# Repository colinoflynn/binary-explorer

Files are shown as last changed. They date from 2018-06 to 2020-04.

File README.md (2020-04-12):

# Binary Explorer #

The Binary Explorer board is based on a previous Kickstarter project, and is designed to provide a useful platform for learning about digital logic. Compared to the previous version, the CPLD has been changed to an Altera MAX II which can be used with more recent design software (including on Windows 10). Note the old ("rev 02") version is completely incompatible with the current version, as the entire CPLD and programming interface has changed.

Binary Explorer includes:

- Altera MAX II CPLD which can be disabled to bypass outputs
- Breadboard for building logic circuits
- Switches, LEDs, and 7-segment displays
- Clocks for CPLD

The following is the old rev design, which looks almost identical from the top-side:
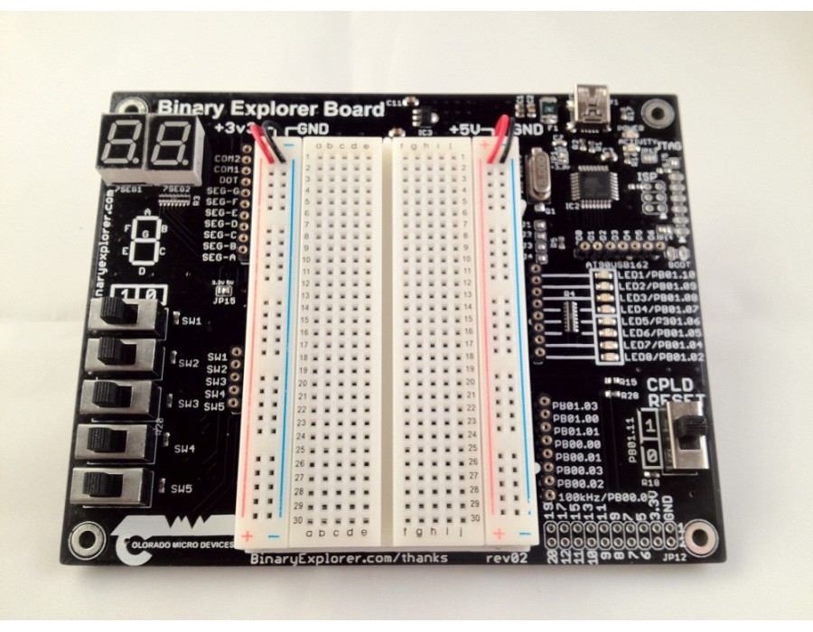
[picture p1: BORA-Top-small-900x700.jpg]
BORA Board


## Reference Designs / Examples ##

A number of templates/examples are provided for the Altera Quartus software. Always use these templates, as they contain considerable critical configuration regarding the device in use and board-specific setting (including pinouts and use of global disable).

If you fail to use these templates and things break, **we will laugh at you when they break**. 

## Using Breadboard ##

To use the breadboard, it's important to set the CPLD to "OFF". The "OFF" position should disable the I/O drivers on the CPLD, but it relies on the CPLD having been configured based on one of the template files.

If you do not set the CPLD to "OFF", or have programmed it with invalid code, you could find certain pins are being driven high/low against your will.

**NEVER use 5.0V on this board** - all I/O will only survive with 3.3V. The board does not include a 5.0V source to avoid this risk, but **DO NOT wire in an external 5.0V source**.

Be sure to **confirm any logic chips you are using** will operate at 3.3V OK.

## USB CPLD Programmer ##

The USB CPLD programming interface is provided thanks to work published at http://sa89a.net/mp.cgi/ele/ub.htm . This pushed the CPLD programming onto one of the lowest-cost USB interface chips which made this entire project possible.

We have adapted this design, with some very minor firmware changes to provide a slow and fast clock to the CPLD. This is often useful during development.

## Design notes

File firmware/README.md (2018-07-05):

# USB Blaster Firmware #

The USB Blaster firmware is based entirely on published work from http://sa89a.net/mp.cgi/ele/ub.htm

The firmware in this repository is a copy of the "0.7" release, and has been slightly updated to include two additional clock outputs:

1) A 50 KHz "fast clock"
2) A 1 Hz "slow clock"

These two clocks are routed to the CPLD, and can be used during development to clock your logic circuits.

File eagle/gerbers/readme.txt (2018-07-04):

Date: June 24, 2018

**********************************************************
PCB Specifications:
 * ROHS Compliant (Lead Free)
 * UL94V-0 Compliant
 * Material: FR-4, 1.6mm
 * Top/Bottom Copper: 0.5 Oz or 1 Oz
 * Top/Bottom Silkscreen Colour: *
 * Top/Bottom Soldermask Colour: Black
 
**********************************************************
Layer Stackup:
 * Top Silkscreen (digital explorer_SILKSCREEN_TOP.gbr)
 * Top Soldermask (digital explorer_SOLDERMASK_BOTTOM.gbr)
 * Top Copper (digital explorer_COPPER_TOP.gbr)
 **** FR4 Material
 * Bottom Copper (digital explorer_COPPER_BOTTOM.gbr)
 * Bottom Soldermask (digital explorer_SOLDERMASK_BOTTOM.gbr)
 * Bottom Silkscreen (digital explorer_SILKSCREEN_BOTTOM.gbr)
 
 Drill file: digital explorer.ncdrill

**********************************************************
Gerber Plotfile Info:
	 Coordinate Format : 2.4
	 Coordinate Units  : Inch
	 Data Mode         : Absolute
	 Zero Suppression  : None
	 End Of Block      : *

NC-Drill File Info:
	 Data Mode         : Absolute
	 Units             : 1/10000 Inch
	 Code  Size       used

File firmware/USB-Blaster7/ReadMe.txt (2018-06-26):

USB-Blasterもどき
マイクロチップのUSBファームウェアVer.2.8をベースに作っています。
再コンパイルする場合下記の環境が必要です。
・MPLAB IDE
・C18 Compiler
・Microchip USB Firmware Ver.2.8(同梱していますので用意する必要はありません)
上記ツールをインストールした上でプロジェクトファイルを開き、
Configure->SelectDevice画面でPIC18F14k50を選択してください。

SPIモジュールの利用と、バイト単位でのIOのため、IOピンが固定となっています。
「BlasterMacros.h」でのピン定義はあくまで命名のためです。
ここだけ変更してもピン配置の変更にはなりません。

・SPI周波数変更
　「BlasterMacros.h」ファイルの13-14行目で切り替え可能です。

・PIO/SPI切り替え
　JTAG通信を高速化するため、PICのMSSPモジュールをSPIモードで利用しています。
　「BlasterMacros.h」ファイル23行目の#define USE_SPIをコメントアウトすると
　SPIモジュールを使わず、プログラムでIOを行います。
　速度は遅くなるので、できればSPIを利用することをお勧めします。

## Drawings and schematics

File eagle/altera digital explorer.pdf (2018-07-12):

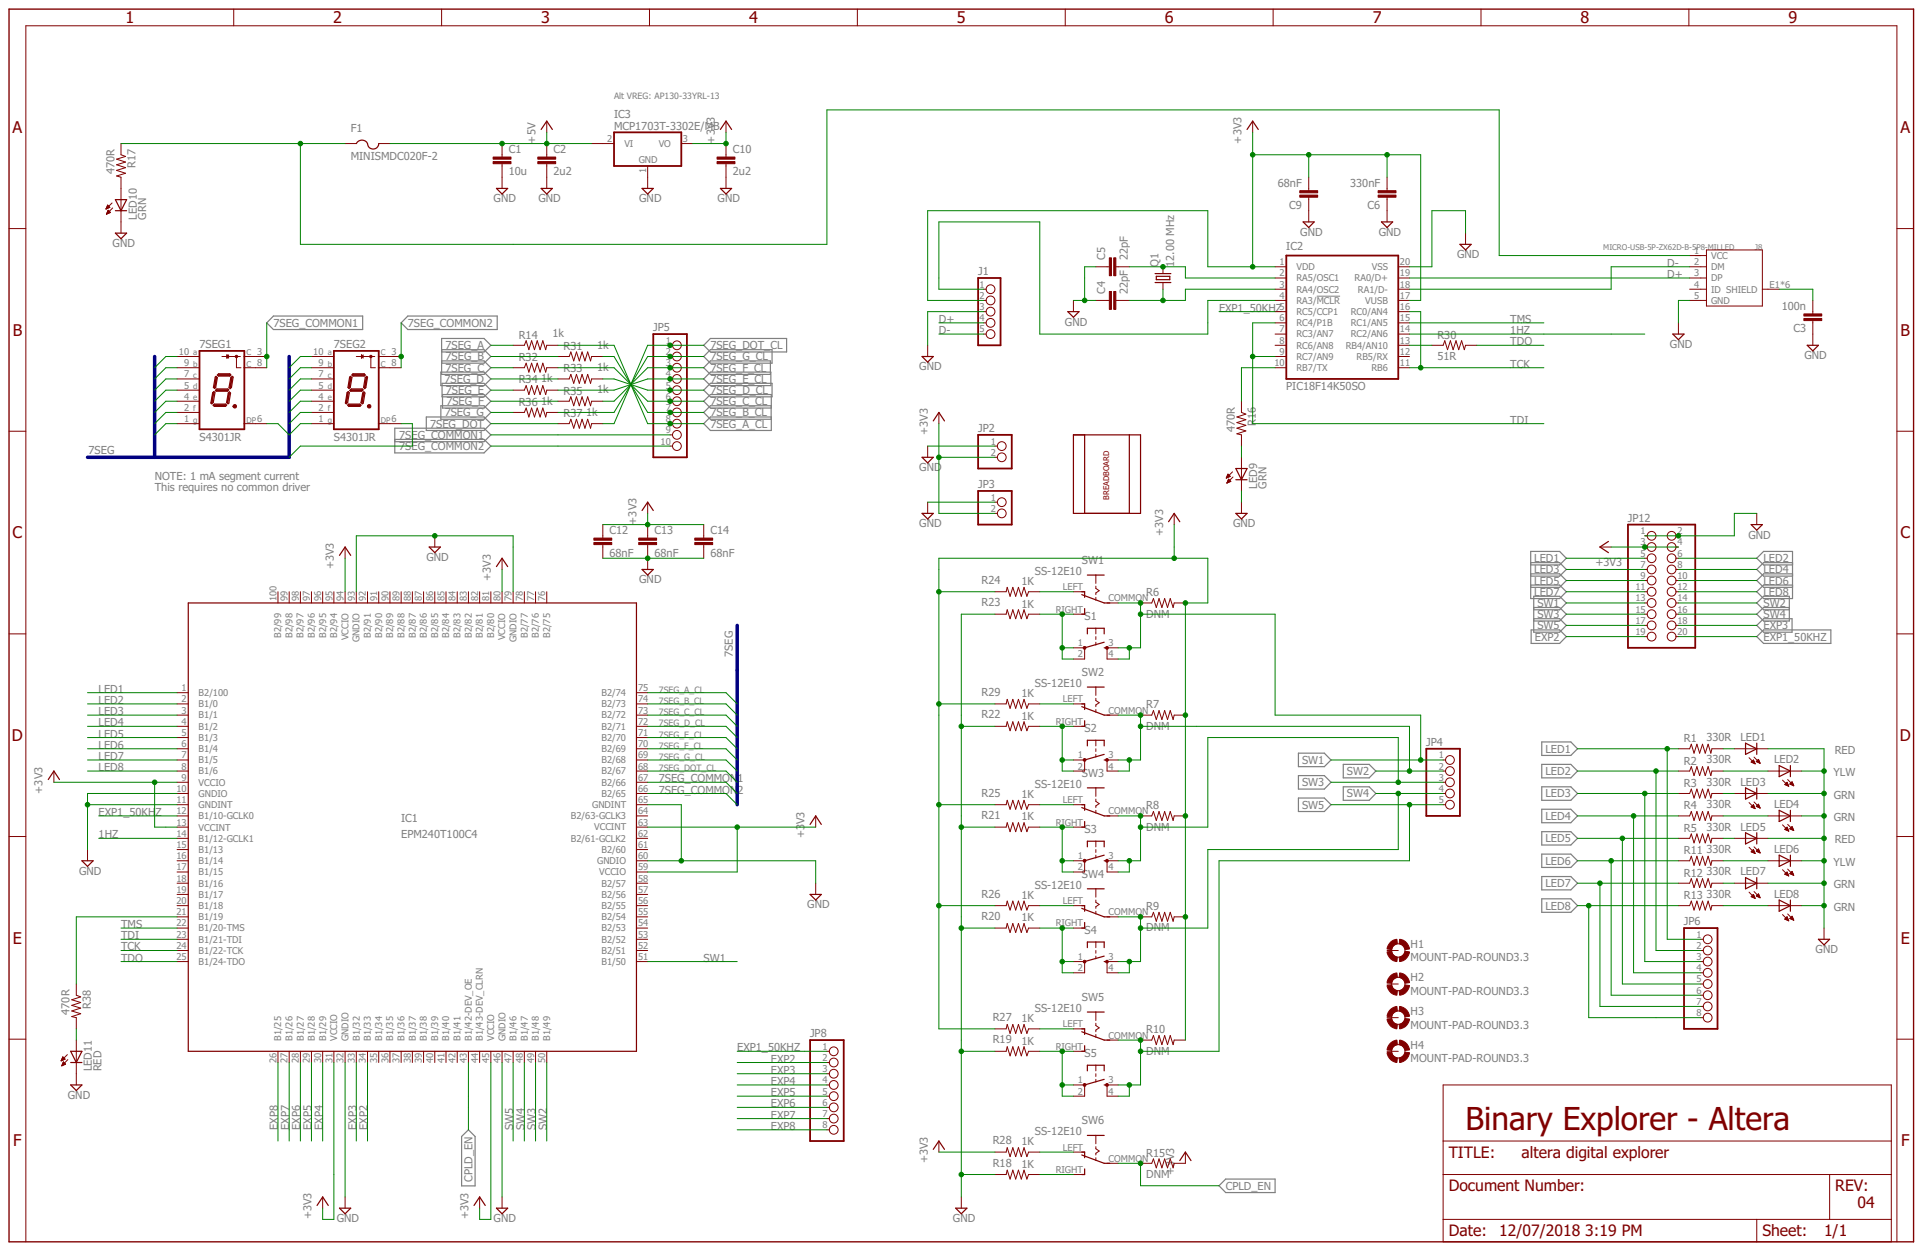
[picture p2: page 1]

NOTE: 1 mA segment current This requires no common driver 7SEG

GND MOUNT-PAD-ROUND3.3 MOUNT-PAD-ROUND3.3 MOUNT-PAD-ROUND3.3 MOUNT-PAD-ROUND3.3

REV: TITLE: Document Number: altera digital explorer

Date: 12/07/2018 3:19 PM | Sheet: 1/1

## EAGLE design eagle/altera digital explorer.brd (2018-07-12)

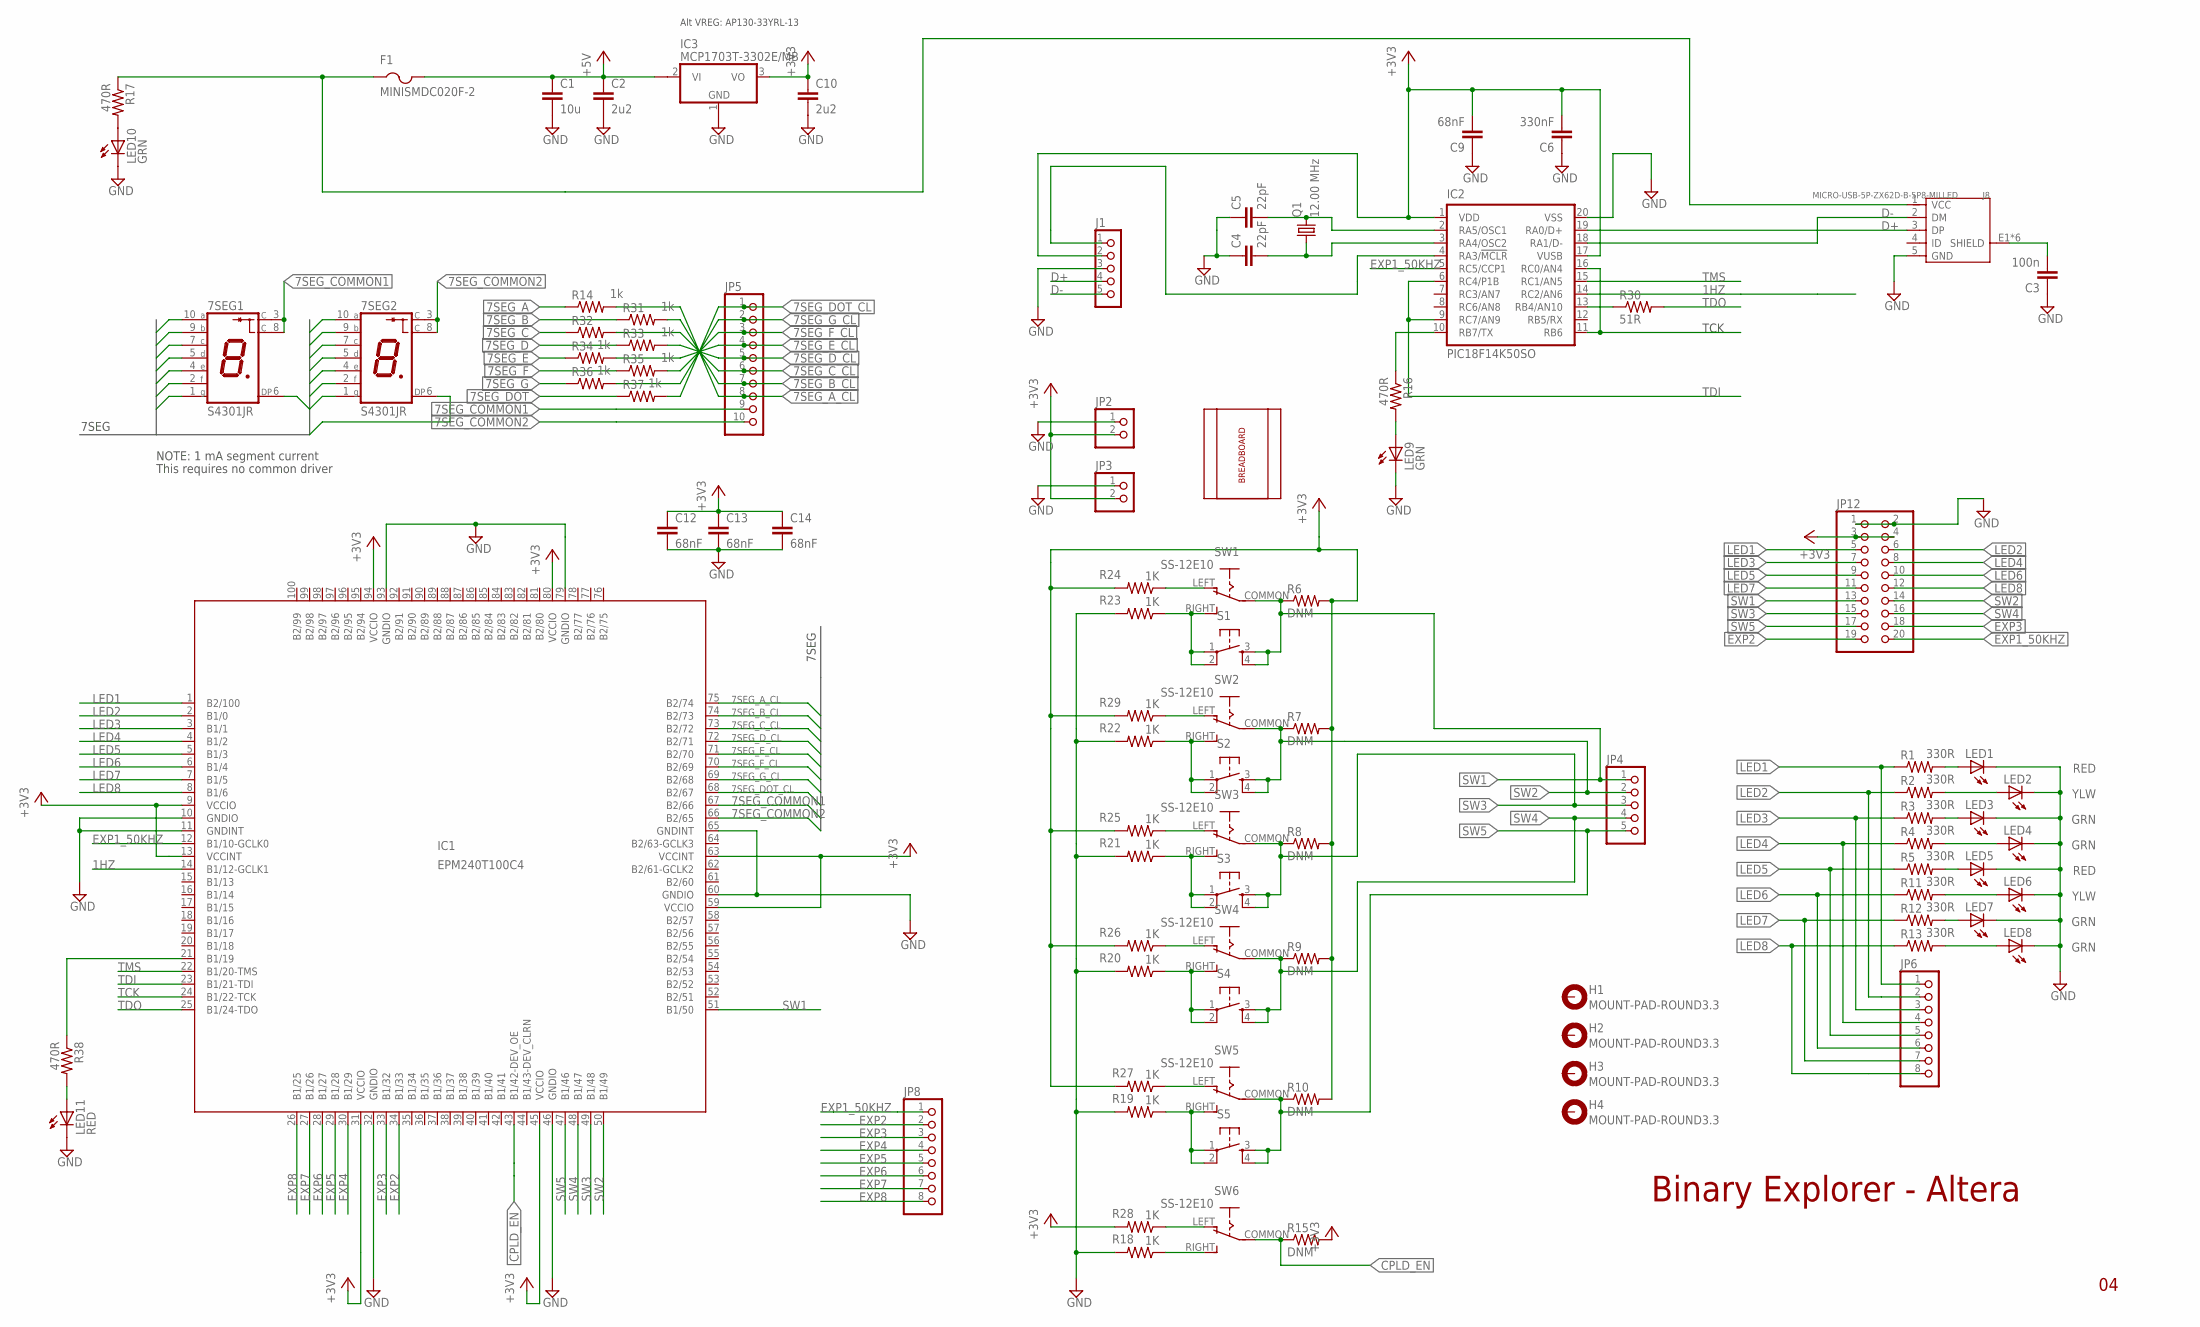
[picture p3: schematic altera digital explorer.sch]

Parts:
7SEG1, 7SEG2: S4301JR; S4301B
C1: 10u; C0805
C2, C10: 2u2; C0805
C3: 100n; C0603
C4, C5: 22pF; C0603
C6: 330nF; C0603
C9, C12, C14: 68nF; C0603
C13: 68nF; C0603K
F1: MINISMDC020F-2; 1812
H1, H2, H3, H4: MOUNT-PAD-ROUND3.3; 3,3-PAD
IC1: EPM240T100C4; TQFP100
IC2: PIC18F14K50SO; SO20
IC3: MCP1703T-3302E/MB; SOT89
J1: CON_HEADER_1X05-PTH; M1X5
J8: MICRO-USB-5P-ZX62D-B-5P8-MILLED; B-SMD-5P-TH-MILLED; MPN ZX62D-B-5P8
JP2, JP3: PINHD-1X2; 1X02
JP4: PINHD-1X5; 1X05
JP5: PINHD-1X10; 1X10
JP6, JP8: PINHD-1X8; 1X08
JP12: PINHD-2X10; 2X10
LED1, LED5, LED11: RED; CHIP-LED0805
LED2, LED6: YLW; CHIP-LED0805
LED3, LED4, LED7, LED8, LED9, LED10: GRN; CHIP-LED0805
Q1: 12.00 MHz; HC49UP; MPN ATS080BSM-1
R1, R2, R3, R4, R5, R11, R12, R13: 330R; R0603
R6, R7, R8, R9, R10, R15: DNM; R0603
R14, R31, R33, R34, R35, R36, R37: 1k; R0603
R16, R17, R38: 470R; R0603
R18, R19, R20, R21, R22, R23, R24, R25, R26, R27, R28, R29: 1K; R0603
R30: 51R; R0603
R32: R-US_R0603; R0603
S1, S2, S3, S4, S5: TAC_SWITCHPTH; TACTILE-PTH
SW1, SW2, SW3, SW4, SW5, SW6: SS-12E10
U$1: BB-400TP

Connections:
1HZ: IC1.14 (B1/12-GCLK1), IC2.14 (RC2/AN6)
7SEG_A: 7SEG1.10 (A), 7SEG2.10 (A), R14.1
7SEG_A_CL: IC1.75 (B2/74), JP5.8, R14.2
7SEG_B: 7SEG1.9 (B), 7SEG2.9 (B), R31.1
7SEG_B_CL: IC1.74 (B2/73), JP5.7, R31.2
7SEG_C: 7SEG1.7 (C), 7SEG2.7 (C), R32.1
7SEG_COMMON1: 7SEG1.3 (C), 7SEG1.8 (C), IC1.67 (B2/66), JP5.9
7SEG_COMMON2: 7SEG2.3 (C), 7SEG2.8 (C), IC1.66 (B2/65), JP5.10
7SEG_C_CL: IC1.73 (B2/72), JP5.6, R32.2
7SEG_D: 7SEG1.5 (D), 7SEG2.5 (D), R33.1
7SEG_DOT: 7SEG1.6 (DP), 7SEG2.6 (DP), R37.1
7SEG_DOT_CL: IC1.68 (B2/67), JP5.1, R37.2
7SEG_D_CL: IC1.72 (B2/71), JP5.5, R33.2
7SEG_E: 7SEG1.4 (E), 7SEG2.4 (E), R34.1
7SEG_E_CL: IC1.71 (B2/70), JP5.4, R34.2
7SEG_F: 7SEG1.2 (F), 7SEG2.2 (F), R35.1
7SEG_F_CL: IC1.70 (B2/69), JP5.3, R35.2
7SEG_G: 7SEG1.1 (G), 7SEG2.1 (G), R36.1
7SEG_G_CL: IC1.69 (B2/68), JP5.2, R36.2
+3V3: C6.2, C9.2, C10.1, C12.1, C13.1, C14.1, IC1.9 (VCCIO), IC1.13 (VCCINT), IC1.31 (VCCIO), IC1.45 (VCCIO), IC1.59 (VCCIO), IC1.63 (VCCINT), IC1.80 (VCCIO), IC1.94 (VCCIO), IC2.1 (VDD), IC2.17 (VUSB), IC3.3 (VO), J1.2, JP2.2, JP3.2, JP12.3, JP12.4, R6.2, R7.2, R8.2, R9.2, R10.2, R15.2, R24.2, R25.2, R26.2, R27.2, R28.2, R29.2
+5V: C1.1, C2.1, F1.2, IC3.2@1 (VI1)
CPLD_EN: IC1.43 (B1/42-DEV_OE), R15.1, SW6.COMMON
D+: IC2.19 (RA0/D+), J1.4, J8.3 (DP)
D-: IC2.18 (RA1/D-), J1.5, J8.2 (DM)
EXP1_50KHZ: IC1.12 (B1/10-GCLK0), IC2.5 (RC5/CCP1), JP8.1, JP12.20
EXP2: IC1.34 (B1/33), JP8.2, JP12.19
EXP3: IC1.33 (B1/32), JP8.3, JP12.18
EXP4: IC1.30 (B1/29), JP8.4
EXP5: IC1.29 (B1/28), JP8.5
EXP6: IC1.28 (B1/27), JP8.6
EXP7: IC1.27 (B1/26), JP8.7
EXP8: IC1.26 (B1/25), JP8.8
GND: C1.2, C2.2, C3.1, C4.1, C5.1, C6.1, C9.1, C10.2, C12.2, C13.2, C14.2, IC1.10 (GNDIO), IC1.11 (GNDINT), IC1.32 (GNDIO), IC1.46 (GNDIO), IC1.60 (GNDIO), IC1.65 (GNDINT), IC1.79 (GNDIO), IC1.93 (GNDIO), IC2.20 (VSS), IC3.1 (GND), J1.3, J8.5 (GND), JP2.1, JP3.1, JP12.1, JP12.2, LED1.C, LED2.C, LED3.C, LED4.C, LED5.C, LED6.C, LED7.C, LED8.C, LED9.C, LED10.C, LED11.C, R18.2, R19.2, R20.2, R21.2, R22.2, R23.2
LED1: IC1.1 (B2/100), JP6.1, JP12.5, R1.1
LED2: IC1.2 (B1/0), JP6.2, JP12.6, R2.1
LED3: IC1.3 (B1/1), JP6.3, JP12.7, R3.1
LED4: IC1.4 (B1/2), JP6.4, JP12.8, R4.1
LED5: IC1.5 (B1/3), JP6.5, JP12.9, R5.1
LED6: IC1.6 (B1/4), JP6.6, JP12.10, R11.1
LED7: IC1.7 (B1/5), JP6.7, JP12.11, R12.1
LED8: IC1.8 (B1/6), JP6.8, JP12.12, R13.1
unnamed: IC2.10 (RB7/TX), R16.1
unnamed: LED4.A, R4.2
unnamed: IC2.13 (RB4/AN10), R30.1
unnamed: IC1.21 (B1/19), R38.1
unnamed: R22.1, S2.1, S2.2, SW2.RIGHT (S)
unnamed: F1.1, J8.1 (VCC), R17.1
unnamed: C3.2, J8.E1 (SHIELD), J8.E2 (SHIELD), J8.P$1 (SHIELD), J8.P$2 (SHIELD), J8.P$3 (SHIELD), J8.P$4 (SHIELD)
unnamed: LED11.A, R38.2
unnamed: IC2.4 (RA3/!MCLR!), J1.1
unnamed: LED9.A, R16.2
unnamed: C5.2, IC2.2 (RA5/OSC1), Q1.2
unnamed: C4.2, IC2.3 (RA4/OSC2), Q1.1
unnamed: R20.1, S4.1, S4.2, SW4.RIGHT (S)
unnamed: LED10.A, R17.2
unnamed: R21.1, S3.1, S3.2, SW3.RIGHT (S)
unnamed: R18.1, SW6.RIGHT (S)
unnamed: R19.1, S5.1, S5.2, SW5.RIGHT (S)
unnamed: LED1.A, R1.2
unnamed: R23.1, S1.1, S1.2, SW1.RIGHT (S)
unnamed: LED2.A, R2.2
unnamed: LED3.A, R3.2
unnamed: LED5.A, R5.2
unnamed: LED6.A, R11.2
unnamed: LED7.A, R12.2
unnamed: LED8.A, R13.2
unnamed: R24.1, SW1.LEFT (O)
unnamed: R25.1, SW3.LEFT (O)
unnamed: R26.1, SW4.LEFT (O)
unnamed: R27.1, SW5.LEFT (O)
unnamed: R28.1, SW6.LEFT (O)
unnamed: R29.1, SW2.LEFT (O)
SW1: IC1.51 (B1/50), JP4.1, JP12.13, R6.1, S1.3, S1.4, SW1.COMMON
SW2: IC1.50 (B1/49), JP4.2, JP12.14, R7.1, S2.3, S2.4, SW2.COMMON
SW3: IC1.49 (B1/48), JP4.3, JP12.15, R8.1, S3.3, S3.4, SW3.COMMON
SW4: IC1.48 (B1/47), JP4.4, JP12.16, R9.1, S4.3, S4.4, SW4.COMMON
SW5: IC1.47 (B1/46), JP4.5, JP12.17, R10.1, S5.3, S5.4, SW5.COMMON
TCK: IC1.24 (B1/22-TCK), IC2.11 (RB6), IC2.16 (RC0/AN4)
TDI: IC1.23 (B1/21-TDI), IC2.6 (RC4/P1B), IC2.9 (RC7/AN9)
TDO: IC1.25 (B1/24-TDO), R30.2
TMS: IC1.22 (B1/20-TMS), IC2.15 (RC1/AN5)

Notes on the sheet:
7SEG
Alt VREG: AP130-33YRL-13
TCK
NOTE: 1 mA segment current
This requires no common driver
Binary Explorer - Altera

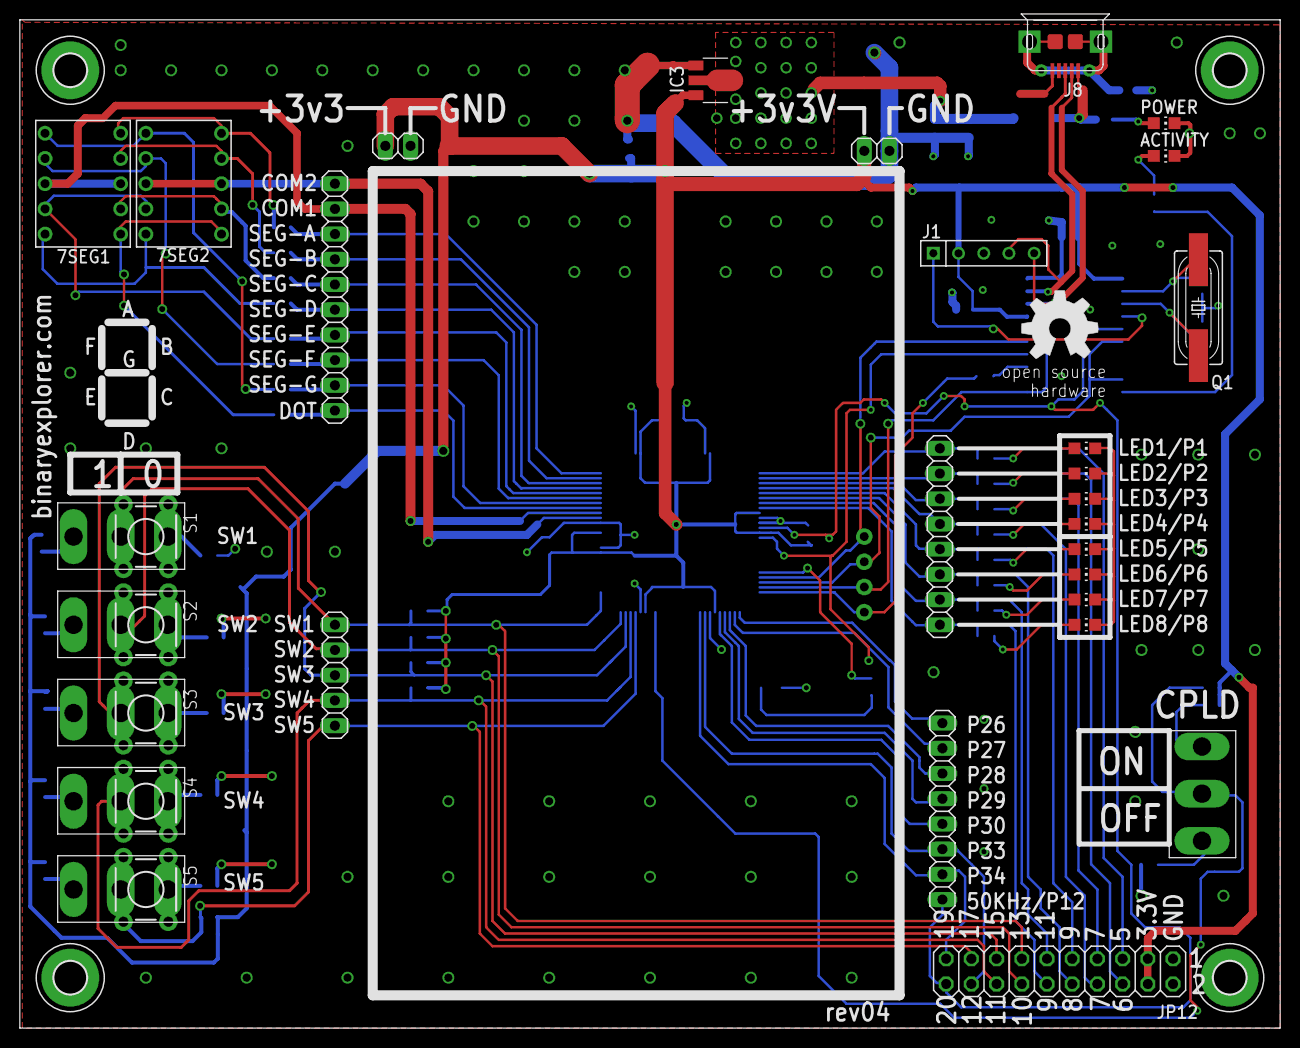
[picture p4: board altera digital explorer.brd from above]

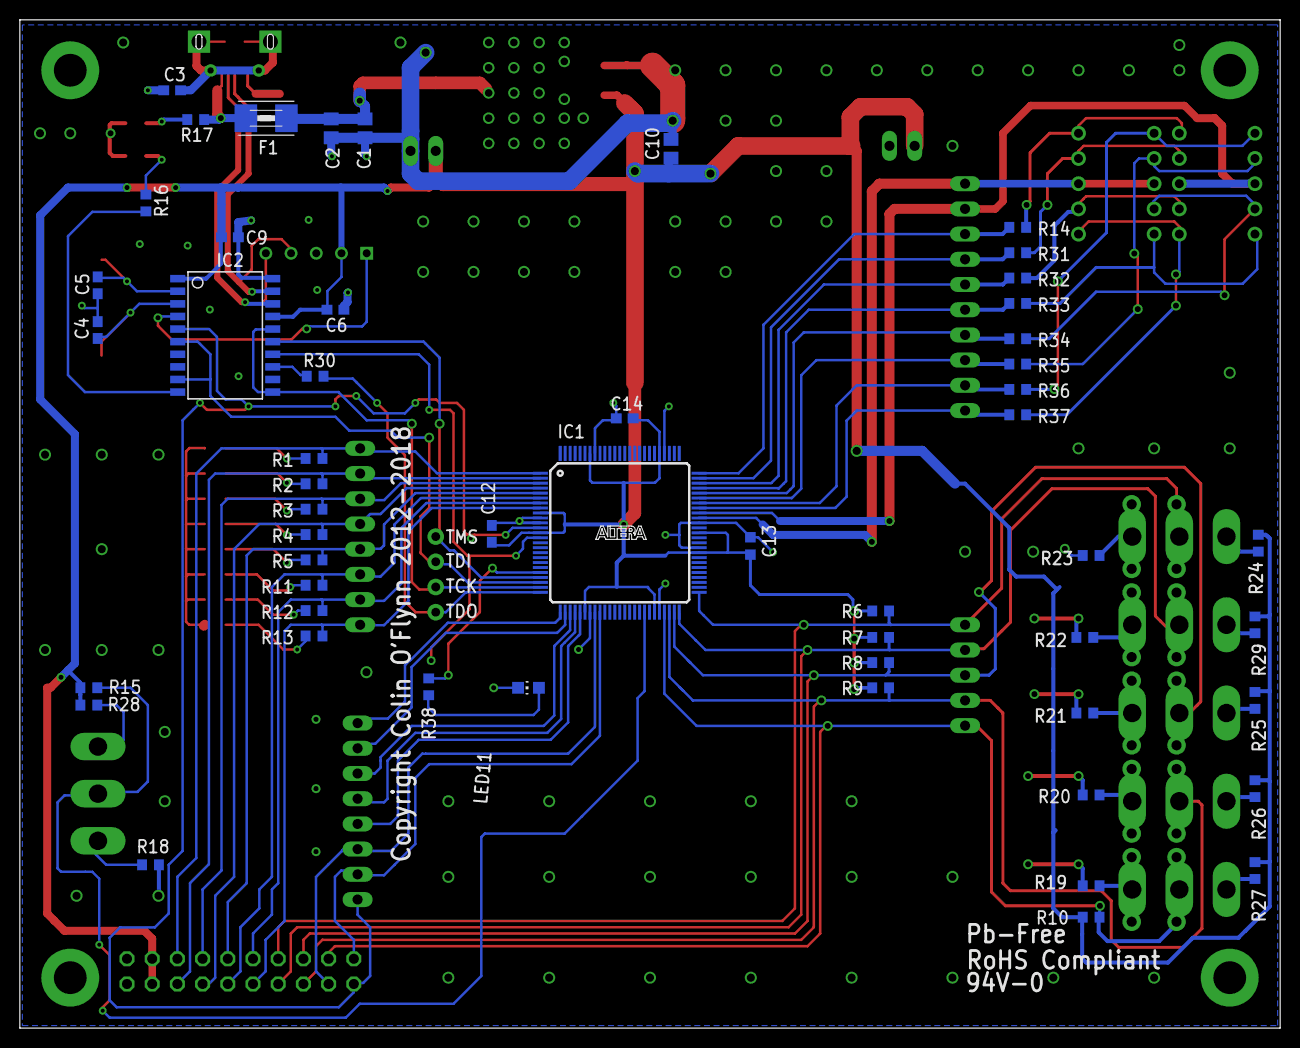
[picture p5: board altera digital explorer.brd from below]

Board: 2 copper layers, 127.0 x 101.6 mm, 93 parts (53 on the bottom side), 81 nets.

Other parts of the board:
U$2: OSHW_8MM

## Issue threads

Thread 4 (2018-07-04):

PCB - bad PIC connections

colinoflynn, 2018-07-04:
PIC connections didn't follow original page but an updated one, the updated one might be wrong. Seems to need double-connections to actually work.

PCB has been modded and eagle updated, but need to commit this and test.

Closed 2018-07-05.

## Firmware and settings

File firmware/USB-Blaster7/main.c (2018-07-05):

// main.c

/** INCLUDES *******************************************************/
#include "./USB/usb.h"
#include "HardwareProfile.h"
//#include "GenericTypeDefs.h"
//#include "Compiler.h"
//#include "usb_config.h"
//#include "USB/usb_device.h"

#include "bitreverse.h"
#include "emu_ft245_eeprom.h"
#include "BlasterMacros.h"

/** CONFIGURATION **************************************************/
#pragma config CPUDIV = NOCLKDIV
#pragma config USBDIV = OFF
#pragma config FOSC   = HS
#pragma config PLLEN  = ON
#pragma config FCMEN  = OFF
#pragma config IESO   = OFF
#pragma config PWRTEN = OFF
#pragma config BOREN  = OFF
#pragma config BORV   = 30
//#pragma config VREGEN = ON
#pragma config WDTEN  = OFF
#pragma config WDTPS  = 32768
#pragma config MCLRE  = OFF
#pragma config HFOFST = OFF
#pragma config STVREN = ON
#pragma config LVP    = OFF
#pragma config XINST  = OFF
#pragma config BBSIZ  = OFF
#pragma config CP0    = OFF
#pragma config CP1    = OFF
#pragma config CPB    = OFF
#pragma config WRT0   = OFF
#pragma config WRT1   = OFF
#pragma config WRTB   = OFF
#pragma config WRTC   = OFF
#pragma config EBTR0  = OFF
#pragma config EBTR1  = OFF
#pragma config EBTRB  = OFF       

/** V A R I A B L E S **********************************************/
#pragma udata USB_VARS
BYTE OutPacket[2][64];
BYTE InPacket[1][64];
extern volatile BYTE CtrlTrfData[8];
#define ctrl_trf_buf CtrlTrfData

#pragma udata access accessram
near BYTE fifo_wp,fifo_rp;		//FIFO Write Pos / Read Pos
near BYTE acc0,acc1;			//AccessRAM for FastTemporaly
near BYTE recv_byte;			//byte count received
near BYTE jtag_byte;			//byte count fot jtag mode
near BYTE aser_byte;			//byte count fot active-serial mode
near BYTE_VAL _flags;
#define read _flags.bits.b0		//simulteneous reading flag
#define received _flags.bits.b1	//OUT Packet Received flag
#ifdef ENABLE_PPB
  #define PPB _flags.bits.b7	//current ping-pong-buffer
  #define TogglePPB() PPB=!PPB 
#else
  #define PPB 0 
  #define TogglePPB()
#endif
near BYTE bufptr;

#pragma udata GP1
BYTE InFIFO[256];

#pragma udata
USB_HANDLE USBOutHandle0;
USB_HANDLE USBOutHandle1;
USB_HANDLE USBInHandle0;

/** P R I V A T E  P R O T O T Y P E S *****************************/
void USBDeviceTasks(void);
void HighIntCode();
void LowIntCode();
void USBCBSendResume(void);

/** VECTOR REMAPPING ***********************************************/
extern void _startup(void);

//Vector Remapping for Standalone Operating
#pragma code HIGH_INTERRUPT_VECTOR = 0x08
void High_ISR(void) { _asm goto 0x1008 _endasm }

#pragma code LOW_INTERRUPT_VECTOR = 0x18
void Low_ISR(void) { _asm goto 0x1018 _endasm }

//Vector Remapping for MCHIP Generic Bootloader
#pragma code GEN_RESET_VECTOR=0x800
void GEN_Reset(void) { _asm goto _startup _endasm }

#pragma code GEN_HIGH_INTERRUPT_VECTOR=0x808
void GEN_HighInt(void) { _asm goto HighIntCode _endasm }

#pragma code GEN_LOW_INTERRUPT_VECTOR=0x818
void GEN_LowInt(void) { _asm goto LowIntCode _endasm }

//Vector Remapping for MCHIP HID Bootloader
#pragma code HID_RESET_VECTOR=0x1000
void HID_Reset(void) { _asm goto _startup _endasm }

#pragma code HID_HIGH_INTERRUPT_VECTOR=0x1008
void HID_HighInt(void) { _asm goto HighIntCode _endasm }

#pragma code HID_LOW_INTERRUPT_VECTOR=0x1018
void HID_LowInt(void) { _asm goto LowIntCode _endasm }

#pragma code
	
#pragma interrupt HighIntCode
void HighIntCode() {
    static unsigned char cnt;
    
    
		//Check which interrupt flag caused the interrupt.
		//Service the interrupt, Clear the interrupt flag, Etc.
        #if defined(USB_INTERRUPT)
	    USBDeviceTasks();
        #endif

        
        if (PIR1bits.TMR1IF) {
            cnt++;
            
            if (cnt > 22){
                LATCbits.LATC2 ^= 1;
                cnt = 0;
            }
            PIR1bits.TMR1IF = 0; 
        } 
        
}	//This return will be a "retfie fast", since this is in a #pragma interrupt section 

#pragma interruptlow LowIntCode
void LowIntCode() {
		//Check which interrupt flag caused the interrupt.
		//Service the interrupt, Clear the interrupt flag, Etc. 
    
	
}	//This return will be a "retfie", since this is in a #pragma interruptlow section 

/** DECLARATIONS ***************************************************/
#pragma code

//for debug use - measure cycle counts
void test(){
	BYTE *p;
	bufptr=64;
	fifo_wp=0;
	fifo_rp=0;
	acc0=0x53;
	acc1=bitreverse[SSPBUF];	//10cy
	enqueue(acc0);		//9cy
	enqueue(acc1);		//9cy
	JTAG_Write(acc0);		//56cy
	JTAG_RW(acc0,acc1);	//73cy
	ASer_RW(acc0,acc1);	//73cy
	dequeue(InPacket[0]+2,fifo_used());	// 116cy@2byte
	fifo_wp=0;for(acc0=0;1;acc0++){enqueue(acc0);if(acc0==255)break;}
	fifo_wp=100; fifo_rp=190;
	dequeue(InPacket[0]+2,62);	//818cy@62byte
	dequeue(InPacket[0]+2,62);	//890cy@62byte
	acc1=bitreverse[OutPacket[0][bufptr++]];	//17cy
	enqueue(bitreverse[SSPBUF]);	//20cy
	Nop();
}

void main(void) {
	//IO Initialize
	ANSEL  = 0;
	ANSELH = 0;
	SLRCON = 0;

	//Port direction setup
	TRISA=0;
	TRISB=0;
	TRISC=0;
	TTDO=1;
	TADO=1;

	//Initial value setup
	OUTP=0b00011010;

	//Peripheral setup
	T0CON=0b10000000;		//On,Fcy/2
	INTCONbits.TMR0IE=0;	//Polling
	#ifdef USE_SPI
	SSPSTAT=0b01000000;		//SMP=0,CKE=1;
	#ifdef SPI_3MHz
	SSPCON1=0b00000001;		//Fspi=3MHz
	#endif
	#ifdef SPI_12MHz
	SSPCON1=0b00000000;		//Fspi=12MHz
	#endif
	ChangePIO();
	#endif	
  
    //Setup clock for fast clock (50 KHz)
    T2CON = 0b00000101; //TMR2ON, FCY/4
    CCP1CONbits.P1M = 0b00;
    CCP1CONbits.CCP1M = 0b1100; //PMW mode
    
    //50KHz output on RC5, set as output
    TRISCbits.TRISC5 = 0;
    PR2 = 60;
    CCPR1L = 30;
    PSTRCON = 0b00000001;
    
    //Setup clock for slow clock (1 Hz)
    //
    TMR1H = 0x00;
    TMR1L = 0x00;
    T1CONbits.T1CKPS1 = 1;
    T1CONbits.T1CKPS0 = 0;
    PIE1bits.TMR1IE = 1;  
    T1CONbits.TMR1ON = 1;
    INTCONbits.PEIE = 1;
    INTCONbits.GIE = 1;

    TRISCbits.RC2 = 0;   
    LATCbits.LATC2 = 0;   
    
	//Program Initialize
	InPacket[0][0]=0x31;
	InPacket[0][1]=0x60;
	eeprom_init();
    USBDeviceInit();
    #if defined(USB_INTERRUPT)
    USBDeviceAttach();
    #endif

//	test();

    while(1) {
        #if defined(USB_POLLING)
        USBDeviceTasks();
        #endif
		
	    if((USBDeviceState < CONFIGURED_STATE)||(USBSuspendControl==1)) {
			//Something to do in not connected to host.
			LACT=0;
		}else{
			//Check and transmit queued data
			if(!USBHandleBusy(USBInHandle0)){
				acc0=fifo_used();
				if(62<=acc0){		//send filled packet to host
					dequeue(InPacket[0]+2,62);
					mUSBTxOnePacket(USBInHandle0,1,InPacket[0],2+62);
					INTCONbits.TMR0IF=1;	//schedule to send indicator			
				}else if(acc0){			//send non-filled packet to host
					dequeue(InPacket[0]+2,acc0);
					mUSBTxOnePacket(USBInHandle0,1,InPacket[0],2+acc0);
					INTCONbits.TMR0IF=1;	//schedule sending indicator
				}else if(INTCONbits.TMR0IF){	//send packet indicator
					TMR0H=5536>>8;	//(65536-5536)/(12000/2)=10ms
					TMR0L=5536&0xFF;
					INTCONbits.TMR0IF=0;
					mUSBTxOnePacket(USBInHandle0,1,InPacket[0],2);
				}
			}
	         //Check to see if data has arrive.
			if(!recv_byte){
				if(PPB==0){	//even packet or no ping-pong
					if(!USBHandleBusy(USBOutHandle0)){
						recv_byte=USBHandleGetLength(USBOutHandle0);
						//p=USBHandleGetAddr(USBOutHandle0);
						bufptr=0;
						received=1;
					}
				}else{		//odd packet
					if(!USBHandleBusy(USBOutHandle1)){
						recv_byte=USBHandleGetLength(USBOutHandle1);
						//p=USBHandleGetAddr(USBOutHandle1);
						bufptr=64;
						received=1;
					}
				}
			}
			if(fifo_able()<recv_byte) continue;	//FIFO Full check
			if(recv_byte){
				LACT=0;
				do{
					if(jtag_byte){
						#ifdef USE_SPI
						ChangeSPI();
						acc0=bitreverse[OutPacket[0][bufptr++]];
						#endif
						if(!read){
							do{
								#ifdef USE_SPI
								SSPBUF=acc0;
								acc0=bitreverse[OutPacket[0][bufptr++]];
								SPI_Wait();
								#else
								acc0=OutPacket[0][bufptr++];
								JTAG_Write(acc0);
								#endif
								jtag_byte--;
								recv_byte--;
							}while(jtag_byte&&recv_byte);
						}else{
							do{
								#ifdef USE_SPI
								SSPBUF=acc0;
								acc0=bitreverse[OutPacket[0][bufptr++]];
								SPI_Wait();
								acc1=bitreverse[SSPBUF];
								enqueue(acc1);
								#else
								acc0=OutPacket[0][bufptr++];
								JTAG_RW(acc0,acc1);
								enqueue(acc1);
								#endif
								jtag_byte--;
								recv_byte--;
							}while(jtag_byte&&recv_byte);
						}
						#ifdef USE_SPI
						bufptr--;
						ChangePIO();
						#endif
					}else if(aser_byte){
						if(!read){
							#ifdef USE_SPI
							ChangeSPI();
							acc0=bitreverse[OutPacket[0][bufptr++]];
							#endif
							do{
								#ifdef USE_SPI
								SSPBUF=acc0;
								acc0=bitreverse[OutPacket[0][bufptr++]];
								SPI_Wait();
								#else
								acc0=OutPacket[0][bufptr++];
								JTAG_Write(acc0);
								#endif
								aser_byte--;
								recv_byte--;
							}while(aser_byte&&recv_byte);
							#ifdef USE_SPI
							bufptr--;
							ChangePIO();
							#endif
						}else{
							do{
								acc0=OutPacket[0][bufptr++];
								ASer_RW(acc0,acc1);
								enqueue(acc1);
								aser_byte--;
								recv_byte--;
							}while(aser_byte&&recv_byte);
						}
					}else{
						do{
							acc0=OutPacket[0][bufptr++];
							bitcopy(bitmask(acc0,6),read);
							if(bitmask(acc0,7)){		//EnterSerialMode
								LTCK=0;		//bug fix
								if(OUTP&0x8){	//nCS=1:JTAG
									jtag_byte=acc0&0x3F;
								}else{		//nCS=0:ActiveSerial
									aser_byte=acc0&0x3F;
								}
								recv_byte--;
								break;
							}else{			//BitBangMode
								OUTP=acc0;
								if(read){
									acc1=0;
									if(PADO) acc1|=0x02;
									if(PTDO) acc1|=0x01;
									enqueue(acc1);
								}
								recv_byte--;
							}
						}while(recv_byte);
					}
				}while(recv_byte);
			}
			if(received&&(!recv_byte)){
				LACT=1;
				if(PPB==0){
					mUSBRxOnePacket(USBOutHandle0,2,OutPacket[0],64);
					TogglePPB();
				}else{
					mUSBRxOnePacket(USBOutHandle1,2,OutPacket[1],64);
					TogglePPB();
				}
				received=0;
			}
		}
    }//end while
}//end main

// ************** USB Callback Functions ****************************
void USBCBSuspend(void) {}
void USBCBWakeFromSuspend(void){}
void USBCB_SOF_Handler(void){}
void USBCBErrorHandler(void){}

extern volatile CTRL_TRF_SETUP SetupPkt;
void USBCBCheckOtherReq(void){
	//FT245 emulation
	BYTE index;
	if(SetupPkt.RequestType==2){	//Vendor request
		if(SetupPkt.DataDir==0){	//0utput
			//Responce by sending zero-length packet
			//I don't know if this way is right, but working:)
			USBEP0SendRAMPtr(ctrl_trf_buf,0,USB_EP0_INCLUDE_ZERO);
			return;
		}
		if(SetupPkt.bRequest==0x90){
			index=(SetupPkt.wIndex<<1)&0x7E;
			ctrl_trf_buf[0]=eeprom_read(index);
			ctrl_trf_buf[1]=eeprom_read(index+1);
		}else{
			ctrl_trf_buf[0]=0x36;
			ctrl_trf_buf[1]=0x83;
		}
		USBEP0SendRAMPtr(ctrl_trf_buf,2,USB_EP0_INCLUDE_ZERO);
	}
}

void USBCBStdSetDscHandler(void){}

void USBCBInitEP(void){
    USBEnableEndpoint(1,USB_IN_ENABLED|USB_HANDSHAKE_ENABLED|USB_DISALLOW_SETUP);
    USBEnableEndpoint(2,USB_OUT_ENABLED|USB_HANDSHAKE_ENABLED|USB_DISALLOW_SETUP);
	USBOutHandle0=0;
	USBOutHandle1=0;
	USBInHandle0=0;
	fifo_wp=0;
	fifo_rp=0;
	recv_byte=0;
    jtag_byte=0;
    aser_byte=0;
	//TODO: Buffer pointer reset
}

void USBCBSendResume(void){
    static WORD delay_count;
    if(USBGetRemoteWakeupStatus() == TRUE){
        if(USBIsBusSuspended() == TRUE){
            USBMaskInterrupts();
            USBCBWakeFromSuspend();
            USBSuspendControl = 0; 
            USBBusIsSuspended = FALSE;
            delay_count = 3600U;        
            do{ delay_count--; }while(delay_count);
            USBResumeControl = 1;       // Start RESUME signaling
            delay_count = 1800U;        // Set RESUME line for 1-13 ms
            do{ delay_count--; }while(delay_count);
            USBResumeControl = 0;       //Finished driving resume signalling
            USBUnmaskInterrupts();
        }
    }
}

#if defined(ENABLE_EP0_DATA_RECEIVED_CALLBACK)
void USBCBEP0DataReceived(void){}
#endif

BOOL USER_USB_CALLBACK_EVENT_HANDLER(USB_EVENT event, void *pdata, WORD size){
    switch(event)
    {
        case EVENT_TRANSFER:
            //Add application specific callback task or callback function here if desired.
            break;
        case EVENT_SOF:
            USBCB_SOF_Handler();
            break;
        case EVENT_SUSPEND:
            USBCBSuspend();
            break;
        case EVENT_RESUME:
            USBCBWakeFromSuspend();
            break;
        case EVENT_CONFIGURED: 
            USBCBInitEP();
            break;
        case EVENT_SET_DESCRIPTOR:
            USBCBStdSetDscHandler();
            break;
        case EVENT_EP0_REQUEST:
            USBCBCheckOtherReq();
            break;
        case EVENT_BUS_ERROR:
            USBCBErrorHandler();
            break;
        case EVENT_TRANSFER_TERMINATED:
            //Add application specific callback task or callback function here if desired.
            //The EVENT_TRANSFER_TERMINATED event occurs when the host performs a CLEAR
            //FEATURE (endpoint halt) request on an application endpoint which was 
            //previously armed (UOWN was = 1).  Here would be a good place to:
            //1.  Determine which endpoint the transaction that just got terminated was 
            //      on, by checking the handle value in the *pdata.
            //2.  Re-arm the endpoint if desired (typically would be the case for OUT 
            //      endpoints).
            break;
        default:
            break;
    }      
    return TRUE; 
}

/** EOF main.c *************************************************/

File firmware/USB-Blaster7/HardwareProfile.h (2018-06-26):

/********************************************************************
 FileName:      HardwareProfile.h
 Dependencies:  See INCLUDES section
 Processor:     PIC18, PIC24, or PIC32 USB Microcontrollers
 Hardware:      The code is natively intended to be used on the 
                  following hardware platforms: 
                    PICDEM�EFS USB Demo Board
                    PIC18F46J50 FS USB Plug-In Module
                    PIC18F87J50 FS USB Plug-In Module
                    Explorer 16 + PIC24 or PIC32 USB PIMs
                    PIC24F Starter Kit
                    Low Pin Count USB Development Kit
                  The firmware may be modified for use on other USB 
                    platforms by editing this file (HardwareProfile.h)
 Compiler:  	Microchip C18 (for PIC18), C30 (for PIC24), 
                  or C32 (for PIC32)
 Company:       Microchip Technology, Inc.

 Software License Agreement:

 The software supplied herewith by Microchip Technology Incorporated
 (the “Company�E for its PIC® Microcontroller is intended and
 supplied to you, the Company’s customer, for use solely and
 exclusively on Microchip PIC Microcontroller products. The
 software is owned by the Company and/or its supplier, and is
 protected under applicable copyright laws. All rights are reserved.
 Any use in violation of the foregoing restrictions may subject the
 user to criminal sanctions under applicable laws, as well as to
 civil liability for the breach of the terms and conditions of this
 license.

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
********************************************************************
 File Description:

 Change History:
  Rev   Date         Description
  1.0   11/19/2004   Initial release
  2.1   02/26/2007   Updated for simplicity and to use common
                     coding style
  2.3   09/15/2008   Broke out each hardware platform into its own
                     "HardwareProfile - xxx.h" file
********************************************************************/

#ifndef HARDWARE_PROFILE_H
#define HARDWARE_PROFILE_H


    /*******************************************************************/
    /******** USB stack hardware selection options *********************/
    /*******************************************************************/
    //This section is the set of definitions required by the MCHPFSUSB
    //  framework.  These definitions tell the firmware what mode it is
    //  running in, and where it can find the results to some information
    //  that the stack needs.
    //These definitions are required by every application developed with
    //  this revision of the MCHPFSUSB framework.  Please review each
    //  option carefully and determine which options are desired/required
    //  for your application.

    //#define USE_SELF_POWER_SENSE_IO	
    #define tris_self_power     TRISAbits.TRISA2    // Input
    #if defined(USE_SELF_POWER_SENSE_IO)
    #define self_power          PORTAbits.RA2
    #else
    #define self_power          1
    #endif

    //#define USE_USB_BUS_SENSE_IO
    #define tris_usb_bus_sense  TRISAbits.TRISA1    // Input
    #if defined(USE_USB_BUS_SENSE_IO)
    #define USB_BUS_SENSE       PORTAbits.RA1
    #else
    #define USB_BUS_SENSE       1
    #endif

    /******** Application specific definitions *************************/

    //Uncomment the following line to make the output HEX of this 
    //  project work with the HID Bootloader
    #define PROGRAMMABLE_WITH_USB_HID_BOOTLOADER	

    #define CLOCK_FREQ 48000000
    #define GetSystemClock() CLOCK_FREQ
 

    /** I/O pin definitions ********************************************/
    #define INPUT_PIN 1
    #define OUTPUT_PIN 0

#endif  //HARDWARE_PROFILE_H

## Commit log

2018-06-26 Initial addition of materials
    [altera digital explorer.brd, altera digital explorer.sch]
2018-06-26 Updates - make schematic nicer, make PDF
    [altera digital explorer.sch]
2018-07-04 PCB update: fix incorrect routing of JTAG programming outputs, change lighthouse to be CPLD controlled, add pushbuttons in addition to switch
    [altera digital explorer.brd, altera digital explorer.sch]
2018-07-05 FW: Fix clock outputs so they work (closes #3)
    [main.c]
2018-07-05 Fix bad pin numbering (closes #1) other minor additions
    [altera digital explorer.brd]
2018-07-05 Add gerber snapshots
2018-07-05 Add gitigore, add gerber move script
2018-07-05 Fix net name for 32khz-->50khz, update schematic print
    [altera digital explorer.brd, altera digital explorer.sch]
2018-07-12 Small fixes to schematic
    [altera digital explorer.brd, altera digital explorer.sch]
2018-07-12 Continuing clean-up of schematic + pcb. Add hex-file for microchip with the clock outputs all turned on.
    [altera digital explorer.brd, altera digital explorer.sch]

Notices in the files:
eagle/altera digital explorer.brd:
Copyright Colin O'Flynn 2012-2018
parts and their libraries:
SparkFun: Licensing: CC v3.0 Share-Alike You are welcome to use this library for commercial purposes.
